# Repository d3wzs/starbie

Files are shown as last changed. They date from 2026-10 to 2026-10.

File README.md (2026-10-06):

# starbie

My starbie. In my variation of the starbie ive moved many of the comopenents around to have a cleaner and more organized front side. Its got a cool star design, inspired by a tomagotchi. 

Screenshot 2026-10-05 at 8 15 34 PM

Screenshot 2026-10-05 at 8 15 26 PM

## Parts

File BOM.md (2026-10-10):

# Starbie – bill of materials

<!-- Generated by Half Life from project cmuvdiqbu00kp01rk4xfdjdbk. Edits here are overwritten on the next sync. -->
<!-- Generated: 2026-10-09T00:31:55.839Z -->

> [!NOTE]
> This parts list is mirrored from [Half Life](https://halflife.hackclub.com). Editing it here will not change the platform's copy, and the next sync overwrites this file.

| Week | Tier | Parts funding |
| --- | --- | --- |
| Week 1 | Tier 1 | $30.00 |

| Part | What it's for | Qty | Unit | Total | Vendor |
| --- | --- | --- | --- | --- | --- |
| [XIAO ESP32 C3](https://www.seeedstudio.com/Seeed-XIAO-ESP32C3-p-5431.html) | Main loop | 1 | $4.90 | $4.90 | [Seeedstudio](https://www.seeedstudio.com/Seeed-XIAO-ESP32C3-p-5431.html) |
| [0.96 OLED](https://www.amazon.com/dp/B0GBVWBWCR) | displaying | 1 | $5.99 | $5.99 | [Amazon](https://www.amazon.com/dp/B0GBVWBWCR) |
| [MPU6050](https://www.amazon.com/2PCS-Unsoldered-GY-521-MPU6050-Sensor/dp/B0H9JC8XZL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) | sensing movement | 1 | $2.79 | $2.79 | [Amazon](https://www.amazon.com/2PCS-Unsoldered-GY-521-MPU6050-Sensor/dp/B0H9JC8XZL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) |
| [DHT11](https://www.amazon.com/DHT-11-Digital-Temperature-Humidity-Arduino/dp/B0CRRXJ83F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) | sensing temp/humidity | 1 | $3.78 | $3.78 | [Amazon](https://www.amazon.com/DHT-11-Digital-Temperature-Humidity-Arduino/dp/B0CRRXJ83F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) |
| [MX Switches](https://www.amazon.com//dp/B0FQP8VYX4) | clicking/interacting | 2 | $0.18 | $0.36 | [Amazon](https://www.amazon.com//dp/B0FQP8VYX4) |
| [Keycaps](https://www.amazon.com/dp/B0CQ2XG16M?th=1) | making keys pleasent to click | 2 | $0.60 | $1.20 | [Amazon](https://www.amazon.com/dp/B0CQ2XG16M?th=1) |
| [PCB](https://www.jlcpcb.com/) | connecting parts | 1 | $4.00 | $4.00 | [JLCPCB](https://www.jlcpcb.com/) |
| **Parts subtotal** | — | — | — | **$23.02** | — |
| **Tax & shipping** | — | — | — | **$2.76** | — |
| **Total** | — | — | — | **$25.78** | — |

$4.22 left of the tier's funding.

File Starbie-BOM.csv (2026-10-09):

Item | amount | cost (ea.) | Link
XIAO ESP32 C3 | 1 | 5.00 | https://www.seeedstudio.com/Seeed-XIAO-ESP32C3-p-5431.html
0.96 OLED | 1 | 2.50 | https://www.amazon.com/dp/B0GBVWBWCR
MPU6050 | 1 | 2.29 | https://www.amazon.com/dp/B0943SGP34
DHT11 | 1 | 3.33 | https://www.amazon.com/dp/B0BLG7R99R
MX Switches | 4 | 0.18 | https://www.amazon.com//dp/B0FQP8VYX4
Keycaps | 4 | 0.60 | https://www.amazon.com/dp/B0CQ2VLMVY
10k Resistor | 1 | 0.05 | https://www.amazon.com/dp/B0B4JFPHTW
PCB | 1 | 10.00 | https://www.jlcpcb.com/
Total (each kit) | 1 | 24.95

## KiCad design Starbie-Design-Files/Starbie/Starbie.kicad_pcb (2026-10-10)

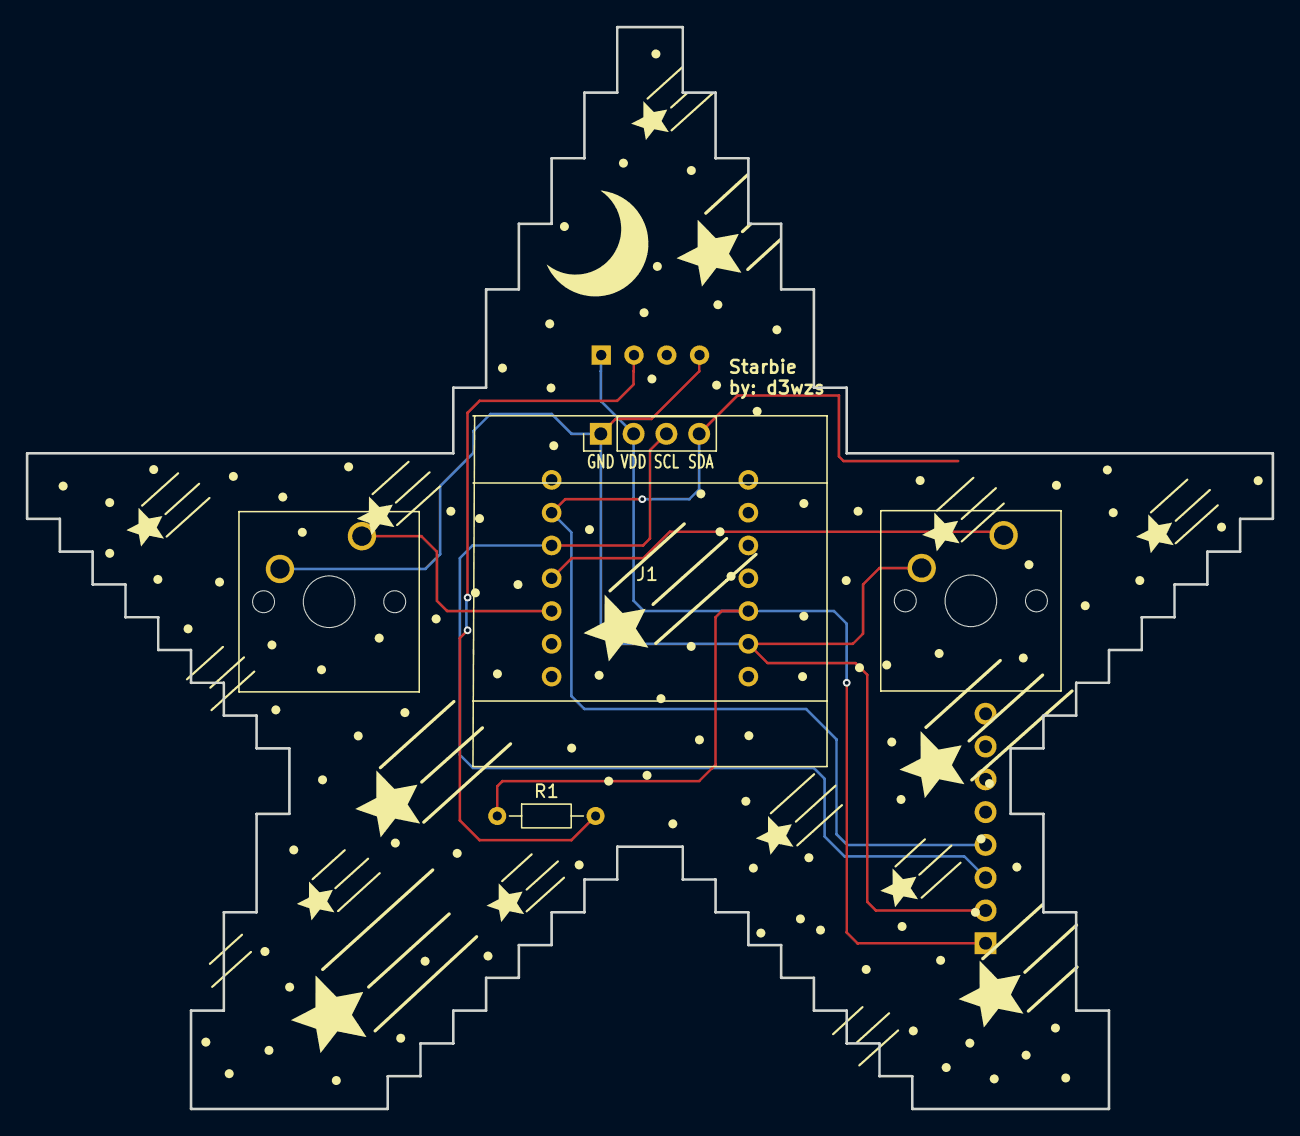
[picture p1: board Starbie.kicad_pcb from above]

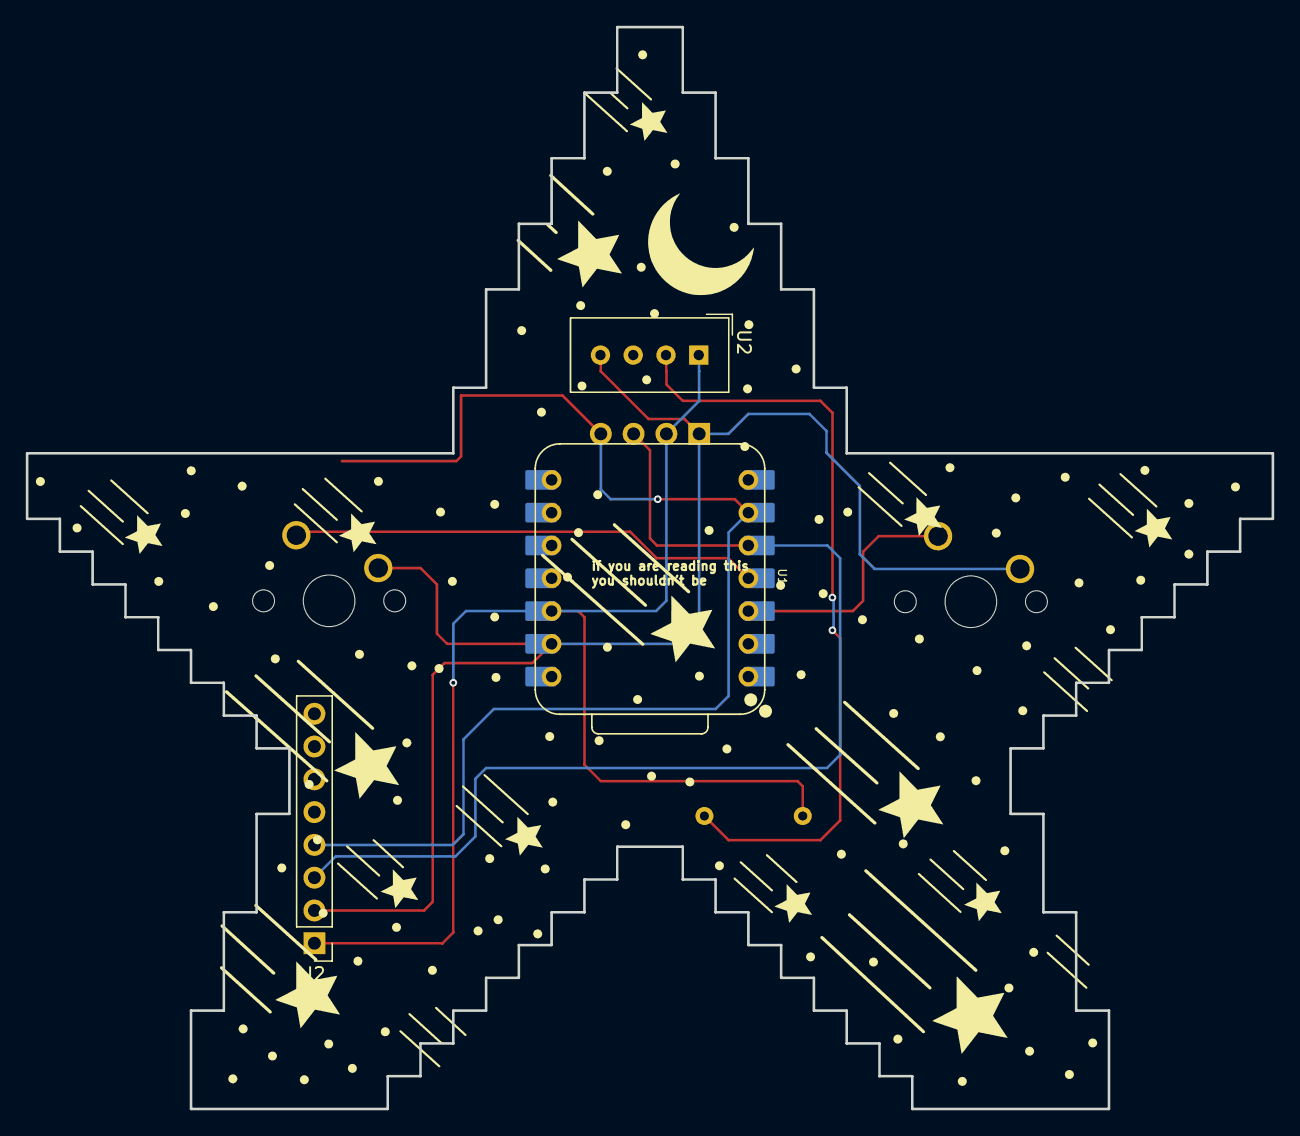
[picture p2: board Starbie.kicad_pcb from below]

Board: 2 copper layers, 96.5 x 83.8 mm, 7 parts (3 on the bottom side), 7 nets.

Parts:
J1: Conn_01x04_Pin; Display_128x64_096_I2C
J2: Conn_01x08_Pin; PinHeader_1x08_P2.54mm_Vertical
R1: 10K; R_Axial_DIN0204_L3.6mm_D1.6mm_P7.62mm_Horizontal
SW1, SW2: SW_Push; SW_Cherry_MX_1.00u_PCB
U1: XIAO-ESP32-C3-SMD; XIAO-ESP32-C6-DIP
U2: DHT11; Aosong_DHT11_5.5x12.0_P2.54mm

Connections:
+3.3V: J1.2, J2.1, R1.1, U1.12 (3V3_OUT), U2.1 (VDD)
/DHT11 DATA: R1.2, U2.2 (DATA)
/GPIO2: SW1.1, U1.3 (D2)
/GPIO3: SW2.1, U1.4 (D3)
/SCL: J1.3, J2.3, U1.5 (D4)
/SDA: J1.4, J2.4, U1.6 (D5)
GND: J1.1, J2.2, SW1.2, SW2.2, U1.13 (GND), U2.4 (GND)

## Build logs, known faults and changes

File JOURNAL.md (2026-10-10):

# Starbie – devlog

<!-- Generated by Half Life from project cmuvdiqbu00kp01rk4xfdjdbk. Edits here are overwritten on the next sync. -->
<!-- Generated: 2026-10-10T02:43:33.424Z -->

> [!NOTE]
> This devlog is mirrored from [Half Life](https://halflife.hackclub.com). Editing it here will not change the platform's copy, and the next sync overwrites this file.

> A tiny motion-controlled digital pet, basically a desktop Tamagotchi. Totally not a Starboy.

| Week | Tier | Hours logged | Entries |
| --- | --- | --- | --- |
| Week 1 | Tier 1 | 14.2h | 6 |

## Contents

1. [2026-10-05 – Created the schematic, then routed the board. I have yet to test it. Im going to try to get feedback on it from my friend who knowsmore then me. I wasted a good 45 mins trying to make a perfect star,](#2026-10-05-created-the-schematic-then-routed-the-board-i-hav)
2. [2026-10-05 – I worked on the PCB more now. I spent a good bit of time designing this shooting star pattern. Im hopping that the main board being behind the display wont be a problem, as well as there being no grou](#2026-10-05-i-worked-on-the-pcb-more-now-i-spent-a-good-bit-o)
3. [2026-10-06 – Variations!!](#2026-10-06-variations)
4. [2026-10-06 – Well that took longer then expected.](#2026-10-06-well-that-took-longer-then-expected)
5. [2026-10-08 – 14 hours for a bambu lab a1.](#2026-10-08-14-hours-for-a-bambu-lab-a1)
6. [2026-10-09 – Well I think its about time that I submit,](#2026-10-09-well-i-think-its-about-time-that-i-submit)

## Design

### 2026-10-05 – Created the schematic, then routed the board. I have yet to test it. Im going to try to get feedback on it from my friend who knowsmore then me. I wasted a good 45 mins trying to make a perfect star,

**3.3h**

Created the schematic, then routed the board. I have yet to test it. Im going to try to get feedback on it from my friend who knowsmore then me. I wasted a good 45 mins trying to make a perfect star, but then gave up and made my own version of a blocky star. I plan to add mounting holes to the design for future purposes as theres is space.

Screenshot 2026-10-05 at 5.34.42 PM

Screenshot 2026-10-05 at 5.34.16 PM

Screenshot 2026-10-05 at 5.34.02 PM

Screenshot 2026-10-05 at 5.33.51 PM

### 2026-10-05 – I worked on the PCB more now. I spent a good bit of time designing this shooting star pattern. Im hopping that the main board being behind the display wont be a problem, as well as there being no grou

**1.9h**

I worked on the PCB more now. I spent a good bit of time designing this shooting star pattern. Im hopping that the main board being behind the display wont be a problem, as well as there being no ground fill. Otherwise a slightly moved some compenents to make the board look better. Design Rules checker is all good, done for today.

Screenshot 2026-10-05 at 8.15.34 PM

Screenshot 2026-10-05 at 8.15.26 PM

### 2026-10-06 – Variations!!

**1.3h**

Variations!!

I decided that I would use the time I had this morning to work on my skills. More specifically my pcb routing skills. I routed a left button and right button variaty of my starbie. I had to move a few compents to fit the buttons in their spots however I think that the staarbies have kept their clean design.

Last night I read the journal guide. They are asking for alot, not something thats impossible, however it seems like something I would not look forward to. It kinda feels like an ELA class, which is something I want to get away from whilst doing these projects. However I will still try my best to make a nice journal.

I also added a few new decals in different spots to cover up the space from where the compenents where moved.

(edit: changed time from 1.2 - 1.3 because I realized at school that 1.2 is not one hour and 20 minutes, tuesday mornings am i right?)

Screenshot 2026-10-06 at 8.40.35 AM

Screenshot 2026-10-06 at 8.40.10 AM

### 2026-10-06 – Well that took longer then expected.

**2.7h**

Well that took longer then expected.

I was doing it completely wrong, I had no idea how to export the gerber files. That took up an hour of my time,  I could have been doing something better in that time but i learned something so thats what matters.

I read through the code that is provided and tried to understand what I could. I changed the starting values but thats It. I plan to do more with the code. I made a few changes to the pcbs but nothing major whatsoever

A big part of this time was spent doing organization. All of my files where scattered around my computer and many things needed to be added to the github. So I organized both my github repo and my computer. All the different versions of my stary starbie are in the repo

Ive been wondering how points are giving, maybe ill look through the documentation a little bit to find information. Is it aset amount for your time, you work or up to someone based of how good your project is? Very curious about this.

Thanks for reading, if you skipped to this, well idk.
Screenshot 2026-10-06 at 4.50.43 PM
organization
Screenshot 2026-10-06 at 4.48.26 PM
organization
Screenshot 2026-10-06 at 4.49.58 PM
seriously I dont know what else to say but organization.
Screenshot 2026-10-06 at 4.52.51 PM\
the impossible to get gerbers.

### 2026-10-08 – 14 hours for a bambu lab a1.

**2h**

14 hours for a bambu lab a1.

It seems like an impossible goal. But i will keep trying. Today I worked on basically just 2 things, one that was much harder and more confusing then the other.

First, the easier one, coding. I worked on coding the nescessary things for the starbie. I followed the instructions that are in the documentation, which are quite straight forward. After I finished doing the nescessary coding I uploaded the new version to my github. I might do some more customization of the sprite and more things once the starbie has been built but for now ill leave it.

Secondly (also lastly), I worked on making a bill of materials. At first i exported it from the schematic with help from some tutorials. But then I noticed that the starbie documentation has a bill of materials. So my shortcut finding self used that instead of making my own. I undestand how each switch is 18 cents but you have to buy it in an 100 pack... so does hackclub purchase the 100 pack, give me the 2 that I need then distribute the rest to others. Im considering inquiring about this.

Thanks for reading here are some photos =)

Screenshot 2026-10-08 at 5.43.12 PM

Screenshot 2026-10-08 at 5.43.25 PMo

### 2026-10-09 – Well I think its about time that I submit,

**3h**

Well I think its about time that I submit,

I went over a few last things and double checked how the pcb would look with some 3d models. Im not sure where to find 3D models so I just downloaded some moderatly sketchy ones which worked about half of the time. Everything looked good so I moved on from that.

I checked my github for any problems. I tried to calculate shipping but I had issues figuring that out so i just found the tax amount in my home provinces taxe amount. Im sure they will tell me I need to fix something before they approve it, but im not sure what.

Thanks for reading my last starbie design journal (maybe).

EDIT:
Yeah i decided i need those 14 hours for my precious bambu labs A1. So i spent a hot minute (like 2 hours) working on cleaning up the star design on all 3 versions as well as putting it on the back of the board. I added a little bit of text saying 'starbie by d3wzy', yeah yeah its not my original idea but whatever. Then i painfully updated all of the github project files and gerbers. Not a fun time, finally im now finishing this week


attempt at a banner photo


the design with 3d models, i also did it for the left button version.

EDIT IMAGES:


i dont know what to call this

prior to adding design to back

design on back!!

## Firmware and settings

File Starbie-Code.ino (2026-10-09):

#include <Wire.h>
#include <Adafruit_GFX.h>
#include <Adafruit_SSD1306.h>
#include <Adafruit_MPU6050.h>
#include <DHT.h>
#include <Preferences.h>
#include <math.h>

// =========================== BEGINNER SETTINGS ===========================
// Everything most builders will want to customize is in this one section.

// --- Your board's pins ----------------------------------------------------
// These are ESP32-C3 GPIO numbers, with the XIAO pin labels beside them.
const int I2C_SDA_PIN = 6;       // XIAO D4: OLED + MPU6050 SDA
const int I2C_SCL_PIN = 7;       // XIAO D5: OLED + MPU6050 SCL
const int DHT_PIN = 3;           // XIAO D1: DHT11 data
const int BUTTON_ONE_PIN = 4;    // XIAO D2: opens/confirms the radial menu
const int BUTTON_TWO_PIN = 5;    // XIAO D3: shows/hides stats

// Set this to false if your submission does not have a DHT11.
const bool USE_DHT11 = true;

// Most parts use these addresses. Only change them if an I2C scanner says
// your part is different (common OLED alternative: 0x3D).
const uint8_t OLED_ADDRESS = 0x3C;
const uint8_t MPU6050_ADDRESS = 0x68;

// --- Starting stats -------------------------------------------------------
// Stats are 0 to 100. They only change when you select an action or shake
// Starbie; nothing slowly drains while it sits on your desk.
const int STARTING_JOY = 75;
const int STARTING_ENERGY = 75;
const int STARTING_FULLNESS = 65;

// Set true, upload once, then set it back to false if you want a fresh pet.
const bool RESET_SAVED_PET_ON_BOOT = false;

// --- Radial menu ----------------------------------------------------------
// These four actions appear at TOP, RIGHT, BOTTOM, then LEFT in the menu.
// The last word controls the matching little visual reaction.
enum PetReaction {
  NAP_REACTION,
  JUMP_REACTION,
  HEART_REACTION,
  RUN_REACTION,
};

struct MenuItem {
  const char *label;
  int joyChange;
  int energyChange;
  int fullnessChange;
  PetReaction reaction;
};

const MenuItem MENU_ITEMS[] = {
  {"NAP",   1,  18, -4, NAP_REACTION},   // top: sleep and emit Zs
  {"PLAY", 12, -9, -5, RUN_REACTION},    // right: two fast laps + hearts
  {"FEED",  3,  2,  18, JUMP_REACTION},  // bottom: wiggle and jump
  {"PET",   7,  0,  0, HEART_REACTION},  // left: jump and emit hearts
};
const int MENU_ITEM_COUNT = sizeof(MENU_ITEMS) / sizeof(MENU_ITEMS[0]);

// --- Movement feel --------------------------------------------------------
// Bigger MENU_TILT_LIMIT makes the menu ball move less.
const float MENU_TILT_LIMIT = 6.0f;

// MPU6050 orientation: change these settings instead of rewiring your board.
// 1. If the sensor is turned 90 degrees, set SWAP_MPU_AXES to true.
// 2. If a direction feels backwards, change that direction from 1.0f to -1.0f.
const bool SWAP_MPU_AXES = false;
const float MENU_X_DIRECTION = 1.0f;
const float MENU_Y_DIRECTION = -1.0f;

// A small dead zone makes the ball rest in the center until the board is tilted.
const float MENU_CENTER_DEADZONE = 0.8f;
const float SHAKE_THRESHOLD = 7.0f;

// Shake is the only movement that has an effect outside the radial menu.
const int SHAKE_JOY_CHANGE = 5;
const int SHAKE_ENERGY_CHANGE = -2;
const int SHAKE_FULLNESS_CHANGE = -1;

// --- Your pet's bitmap and animation -------------------------------------
// This is a simplified 32 by 32, one-bit version of the supplied character.
// You can replace it with your own art later; keep these size values matched
// to the sprite array you paste in.
const int PET_SPRITE_WIDTH = 32;
const int PET_SPRITE_HEIGHT = 32;

// The pet wanders unless it is asleep. A non-nap action does a tiny shake,
// then a jump, except PLAY which runs two fast laps.
const uint16_t PET_WALK_PIXEL_MS = 70;
const uint16_t PET_PRE_JUMP_MS = 230;
const uint16_t PET_JUMP_MS = 430;
const int PET_JUMP_HEIGHT = 16;
const uint32_t NAP_DURATION_MS = 48000;  // 48 seconds: four times the old nap.
const uint16_t HEARTS_DURATION_MS = 1600;
const uint16_t PLAY_LAP_MS = 800;
const uint8_t PLAY_LAP_COUNT = 2;

// Each byte stores eight pixels, left to right. This sparse outline keeps the
// supplied creature readable on a tiny, one-bit OLED: head, eye, legs, tail,
// and a small flower-like ear accent all stay separate instead of becoming a blob.
const uint8_t PROGMEM PET_SPRITE[] = {
  0x00, 0x00, 0x00, 0x00,
  0x00, 0x00, 0x00, 0x00,
  0x00, 0x00, 0x00, 0x00,
  0x00, 0x00, 0x00, 0x00,
  0x00, 0x00, 0x00, 0x00,
  0x00, 0x00, 0x00, 0x00,
  0x00, 0x70, 0x0a, 0x00,
  0x00, 0xf8, 0x1f, 0x00,
  0x00, 0x8c, 0x3f, 0x80,
  0x00, 0x43, 0xff, 0x00,
  0x00, 0x43, 0xff, 0x00,
  0x00, 0x30, 0x7e, 0x00,
  0x00, 0x98, 0x01, 0x00,
  0x01, 0x98, 0x01, 0x80,
  0x03, 0x00, 0x10, 0xc0,
  0x03, 0x04, 0x00, 0xc0,
  0x01, 0x8b, 0x01, 0x80,
  0x01, 0xcb, 0x03, 0x80,
  0x03, 0xc0, 0x03, 0xc0,
  0x03, 0xc0, 0x03, 0xc0,
  0x01, 0xc0, 0x03, 0x80,
  0x01, 0x80, 0x01, 0x80,
  0x00, 0x60, 0x06, 0x00,
  0x00, 0x3f, 0xfc, 0x00,
  0x00, 0x7f, 0xfe, 0x00,
  0x00, 0x70, 0x0e, 0x00,
  0x00, 0x00, 0x00, 0x00,
  0x00, 0x00, 0x00, 0x00,
  0x00, 0x00, 0x00, 0x00,
  0x00, 0x00, 0x00, 0x00,
  0x00, 0x00, 0x00, 0x00,
  0x00, 0x00, 0x00, 0x00,
};
// ===========================================================================
// You can read below without needing to understand every line. The rest of
// the sketch handles buttons, sensors, drawing, and saving automatically.

const int SCREEN_WIDTH = 128;
const int SCREEN_HEIGHT = 64;
const int MENU_CENTER_X = 64;
const int MENU_CENTER_Y = 32;
const int MENU_ITEM_X[] = {64, 108, 64, 20};
const int MENU_ITEM_Y[] = {12, 32, 53, 32};
const int MENU_BALL_X_RANGE = 37;
const int MENU_BALL_Y_RANGE = 22;
const uint16_t BUTTON_DEBOUNCE_MS = 30;
const uint16_t MPU_READ_INTERVAL_MS = 30;
const uint16_t DHT_READ_INTERVAL_MS = 2200;
const uint16_t SHAKE_COOLDOWN_MS = 650;
const float STANDARD_GRAVITY = 9.80665f;

Adafruit_SSD1306 display(SCREEN_WIDTH, SCREEN_HEIGHT, &Wire, -1);
Adafruit_MPU6050 mpu;
DHT dht(DHT_PIN, DHT11);
Preferences preferences;

struct PetState {
  int joy;
  int energy;
  int fullness;
};

struct ButtonState {
  int pin;
  bool stableState;
  bool lastRawState;
  uint32_t lastChangedAt;
};

enum View {
  PET_VIEW,
  MENU_VIEW,
  STATS_VIEW,
};

PetState pet = {STARTING_JOY, STARTING_ENERGY, STARTING_FULLNESS};
ButtonState buttonOne = {BUTTON_ONE_PIN, HIGH, HIGH, 0};
ButtonState buttonTwo = {BUTTON_TWO_PIN, HIGH, HIGH, 0};
View currentView = PET_VIEW;

bool mpuFound = false;
bool dhtFound = false;
float accelerationX = 0.0f;
float accelerationY = 0.0f;
float accelerationZ = STANDARD_GRAVITY;
float temperatureC = NAN;
float humidity = NAN;
float menuBallX = MENU_CENTER_X;
float menuBallY = MENU_CENTER_Y;
float menuCenterAccelerationX = 0.0f;
float menuCenterAccelerationY = 0.0f;
int selectedMenuItem = -1;
uint32_t lastMpuReadAt = 0;
uint32_t lastDhtReadAt = 0;
uint32_t lastShakeAt = 0;
uint32_t shakeAnimationEndsAt = 0;
uint32_t petJumpStartedAt = 0;
uint32_t nappingUntil = 0;
uint32_t heartAnimationEndsAt = 0;
uint32_t playRunStartedAt = 0;
int nappingPetX = 0;

int petWalkingX(uint32_t now);

int keepInRange(int value, int smallest, int largest) {
  return constrain(value, smallest, largest);
}

void changePet(int joyChange, int energyChange, int fullnessChange) {
  pet.joy = keepInRange(pet.joy + joyChange, 0, 100);
  pet.energy = keepInRange(pet.energy + energyChange, 0, 100);
  pet.fullness = keepInRange(pet.fullness + fullnessChange, 0, 100);
}

void loadPet() {
  preferences.begin("starbie", false);
  if (RESET_SAVED_PET_ON_BOOT) {
    preferences.clear();
  }
  pet.joy = preferences.getInt("joy", STARTING_JOY);
  pet.energy = preferences.getInt("energy", STARTING_ENERGY);
  pet.fullness = preferences.getInt("full", STARTING_FULLNESS);
}

void savePet() {
  preferences.putInt("joy", pet.joy);
  preferences.putInt("energy", pet.energy);
  preferences.putInt("full", pet.fullness);
}

void setUpButton(ButtonState &button) {
  pinMode(button.pin, INPUT_PULLUP);
  button.stableState = digitalRead(button.pin);
  button.lastRawState = button.stableState;
  button.lastChangedAt = millis();
}

// Returns true exactly once for each press, even if the switch bounces.
bool wasPressed(ButtonState &button) {
  const bool rawState = digitalRead(button.pin);
  const uint32_t now = millis();

  if (rawState != button.lastRawState) {
    button.lastRawState = rawState;
    button.lastChangedAt = now;
  }

  if (rawState != button.stableState &&
      now - button.lastChangedAt >= BUTTON_DEBOUNCE_MS) {
    button.stableState = rawState;
    return button.stableState == LOW;
  }

  return false;
}

void updateMpu() {
  if (!mpuFound || millis() - lastMpuReadAt < MPU_READ_INTERVAL_MS) {
    return;
  }
  lastMpuReadAt = millis();

  sensors_event_t acceleration;
  sensors_event_t gyro;
  sensors_event_t sensorTemperature;
  mpu.getEvent(&acceleration, &gyro, &sensorTemperature);
  accelerationX = acceleration.acceleration.x;
  accelerationY = acceleration.acceleration.y;
  accelerationZ = acceleration.acceleration.z;
}

void updateDht() {
  if (!dhtFound || millis() - lastDhtReadAt < DHT_READ_INTERVAL_MS) {
    return;
  }
  lastDhtReadAt = millis();

  const float newHumidity = dht.readHumidity();
  const float newTemperatureC = dht.readTemperature();
  if (!isnan(newHumidity)) {
    humidity = newHumidity;
  }
  if (!isnan(newTemperatureC)) {
    temperatureC = newTemperatureC;
  }
}

int petWalkingX(uint32_t now) {
  const int farthestX = SCREEN_WIDTH - PET_SPRITE_WIDTH;
  const uint32_t roundTrip = static_cast<uint32_t>(farthestX) * 2;
  const uint32_t step = (now / PET_WALK_PIXEL_MS) % roundTrip;
  return step <= farthestX ? step : roundTrip - step;
}

uint32_t playRunDuration() {
  return static_cast<uint32_t>(PLAY_LAP_MS) * PLAY_LAP_COUNT;
}

bool isNapping() {
  return nappingUntil != 0 && millis() < nappingUntil;
}

bool isPlaying() {
  return playRunStartedAt != 0 && millis() - playRunStartedAt < playRunDuration();
}

int playRunX(uint32_t now) {
  const int farthestX = SCREEN_WIDTH - PET_SPRITE_WIDTH;
  const uint32_t lapAge = (now - playRunStartedAt) % PLAY_LAP_MS;
  const float progress = static_cast<float>(lapAge) / PLAY_LAP_MS;
  return progress < 0.5f ? static_cast<int>(progress * 2.0f * farthestX)
                         : static_cast<int>((1.0f - progress) * 2.0f * farthestX);
}

void updatePetTimers() {
  if (nappingUntil != 0 && !isNapping()) {
    nappingUntil = 0;  // The pet wakes naturally when its nap time is over.
  }
  if (playRunStartedAt != 0 && !isPlaying()) {
    playRunStartedAt = 0;  // PLAY is exactly two left-to-right-to-left laps.
  }
}

// While the menu is open, the MPU6050 acts like a tiny air mouse. The position
// at the instant Button 1 opens the menu becomes the center for that menu use.
void updateMenuBall() {
  float xTilt = accelerationX - menuCenterAccelerationX;
  float yTilt = accelerationY - menuCenterAccelerationY;

  if (SWAP_MPU_AXES) {
    const float oldXTilt = xTilt;
    xTilt = yTilt;
    yTilt = oldXTilt;
  }
  xTilt = constrain(xTilt * MENU_X_DIRECTION, -MENU_TILT_LIMIT, MENU_TILT_LIMIT);
  yTilt = constrain(yTilt * MENU_Y_DIRECTION, -MENU_TILT_LIMIT, MENU_TILT_LIMIT);
  const float targetX = MENU_CENTER_X + (xTilt / MENU_TILT_LIMIT) * MENU_BALL_X_RANGE;
  const float targetY = MENU_CENTER_Y + (yTilt / MENU_TILT_LIMIT) * MENU_BALL_Y_RANGE;

  // This small amount of smoothing makes the ball feel less jittery.
  menuBallX += (targetX - menuBallX) * 0.20f;
  menuBallY += (targetY - menuBallY) * 0.20f;

  // The menu has four full sectors, not four tiny targets. Any tilt direction
  // past the center dead zone selects its matching top/right/bottom/left action.
  if (fabsf(xTilt) < MENU_CENTER_DEADZONE && fabsf(yTilt) < MENU_CENTER_DEADZONE) {
    selectedMenuItem = -1;
  } else if (fabsf(xTilt) > fabsf(yTilt)) {
    selectedMenuItem = xTilt > 0.0f ? 1 : 3;  // right or left
  } else {
    selectedMenuItem = yTilt > 0.0f ? 2 : 0;  // bottom or top
  }
}

void checkForShake() {
  if (!mpuFound || currentView != PET_VIEW) {
    return;
  }

  const float magnitude = sqrtf(accelerationX * accelerationX +
                                accelerationY * accelerationY +
                                accelerationZ * accelerationZ);
  const uint32_t now = millis();
  if (fabsf(magnitude - STANDARD_GRAVITY) >= SHAKE_THRESHOLD &&
      now - lastShakeAt >= SHAKE_COOLDOWN_MS) {
    lastShakeAt = now;
    nappingUntil = 0;  // A shake wakes a sleeping pet right away.
    shakeAnimationEndsAt = now + 350;
    changePet(SHAKE_JOY_CHANGE, SHAKE_ENERGY_CHANGE, SHAKE_FULLNESS_CHANGE);
    savePet();
  }
}

void openMenu() {
  currentView = MENU_VIEW;
  selectedMenuItem = -1;
  menuBallX = MENU_CENTER_X;
  menuBallY = MENU_CENTER_Y;
  // Calibrate here so every menu starts from however the builder is holding it.
  menuCenterAccelerationX = accelerationX;
  menuCenterAccelerationY = accelerationY;
}

void chooseMenuItem() {
  if (selectedMenuItem == -1) {
    return;  // Keep the menu open until the ball reaches a choice.
  }

  const MenuItem &item = MENU_ITEMS[selectedMenuItem];
  changePet(item.joyChange, item.energyChange, item.fullnessChange);
  savePet();
  const uint32_t now = millis();
  nappingUntil = 0;
  heartAnimationEndsAt = 0;
  playRunStartedAt = 0;

  if (item.reaction == NAP_REACTION) {
    petJumpStartedAt = 0;
    nappingPetX = petWalkingX(now);
    nappingUntil = now + NAP_DURATION_MS;
  } else if (item.reaction == RUN_REACTION) {
    petJumpStartedAt = 0;
    playRunStartedAt = now;
    heartAnimationEndsAt = now + playRunDuration();
  } else {
    // A confirmed action gets a little anticipation shake before the jump.
    petJumpStartedAt = now;
    if (item.reaction == HEART_REACTION) {
      heartAnimationEndsAt = now + HEARTS_DURATION_MS;
    }
  }
  currentView = PET_VIEW;
}

void handleButtons() {
  if (wasPressed(buttonOne)) {
    if (currentView == MENU_VIEW) {
      chooseMenuItem();
    } else {
      openMenu();
    }
  }

  if (wasPressed(buttonTwo)) {
    // Button 2 never changes the pet. It only lets you peek at the values.
    currentView = currentView == STATS_VIEW ? PET_VIEW : STATS_VIEW;
  }
}

void drawSparkle(int x, int y) {
  display.drawPixel(x, y - 2, SSD1306_WHITE);
  display.drawPixel(x - 1, y - 1, SSD1306_WHITE);
  display.drawPixel(x + 1, y - 1, SSD1306_WHITE);
  display.drawPixel(x - 2, y, SSD1306_WHITE);
  display.drawPixel(x, y, SSD1306_WHITE);
  display.drawPixel(x + 2, y, SSD1306_WHITE);
  display.drawPixel(x - 1, y + 1, SSD1306_WHITE);
  display.drawPixel(x + 1, y + 1, SSD1306_WHITE);
  display.drawPixel(x, y + 2, SSD1306_WHITE);
}

void drawHeart(int x, int y) {
  // A tiny seven-pixel-wide heart that stays crisp on the OLED.
  display.fillRect(x - 2, y, 2, 2, SSD1306_WHITE);
  display.fillRect(x + 1, y, 2, 2, SSD1306_WHITE);
  display.fillRect(x - 3, y + 2, 7, 2, SSD1306_WHITE);
  display.fillRect(x - 2, y + 4, 5, 1, SSD1306_WHITE);
  display.fillRect(x - 1, y + 5, 3, 1, SSD1306_WHITE);
  display.drawPixel(x, y + 6, SSD1306_WHITE);
}

void drawHearts(uint32_t now, int petX, int petY) {
  if (now >= heartAnimationEndsAt) {
    return;
  }

  const float progress =
      1.0f - static_cast<float>(heartAnimationEndsAt - now) / HEARTS_DURATION_MS;
  const int rise = static_cast<int>(progress * 18.0f);
  drawHeart(petX + 10, petY - 3 - rise);
  drawHeart(petX + 22, petY - 9 - rise / 2);
}

void drawSleepZs(uint32_t now, int petX, int petY) {
  // The Zs float upward, then loop back down while the pet is napping.
  const int rise = static_cast<int>((now / 300UL) % 15UL);
  display.setTextSize(1);
  display.setTextColor(SSD1306_WHITE);
  display.setCursor(petX + 23, petY - 2 - rise);
  display.print("z");
  display.setCursor(petX + 28, petY - 8 - rise / 2);
  display.print("z");
}

void drawPet() {
  display.clearDisplay();

  const uint32_t now = millis();
  int petX = isNapping() ? nappingPetX : petWalkingX(now);
  if (isPlaying()) {
    petX = playRunX(now);
  }
  int petY = SCREEN_HEIGHT - PET_SPRITE_HEIGHT;

  // The pet always wanders except during a nap; PLAY temporarily takes over.
  if (now < shakeAnimationEndsAt) {
    petX += static_cast<int>(sinf(now / 18.0f) * 3.0f);
  }

  if (!isNapping() && petJumpStartedAt != 0) {
    const uint32_t animationAge = now - petJumpStartedAt;

    if (animationAge < PET_PRE_JUMP_MS) {
      petX += static_cast<int>(sinf(now / 16.0f) * 3.0f);
    } else if (animationAge < PET_PRE_JUMP_MS + PET_JUMP_MS) {
      const float jumpProgress =
          static_cast<float>(animationAge - PET_PRE_JUMP_MS) / PET_JUMP_MS;
      petY -= static_cast<int>(sinf(jumpProgress * PI) * PET_JUMP_HEIGHT);
    } else {
      petJumpStartedAt = 0;
    }
  }

  petX = constrain(petX, 0, SCREEN_WIDTH - PET_SPRITE_WIDTH);
  display.drawBitmap(petX, petY, PET_SPRITE, PET_SPRITE_WIDTH, PET_SPRITE_HEIGHT, SSD1306_WHITE);
  if (!isNapping() && (now / 250) % 2 == 0) {
  drawSparkle(petX - 4, petY + 18);
  }

  if (isNapping()) {
    drawSleepZs(now, petX, petY);
  }
  drawHearts(now, petX, petY);
}

void drawMenuItem(int item) {
  const int boxWidth = 33;
  const int boxHeight = 12;
  const int boxX = MENU_ITEM_X[item] - boxWidth / 2;
  const int boxY = MENU_ITEM_Y[item] - boxHeight / 2;
  const bool isSelected = item == selectedMenuItem;

  if (isSelected) {
    display.fillRoundRect(boxX, boxY, boxWidth, boxHeight, 3, SSD1306_WHITE);
    display.setTextColor(SSD1306_BLACK);
  } else {
    display.drawRoundRect(boxX, boxY, boxWidth, boxHeight, 3, SSD1306_WHITE);
    display.setTextColor(SSD1306_WHITE);
  }

  display.setTextSize(1);
  const int labelLength = strlen(MENU_ITEMS[item].label);
  display.setCursor(MENU_ITEM_X[item] - labelLength * 3, MENU_ITEM_Y[item] - 3);
  display.print(MENU_ITEMS[item].label);
  display.setTextColor(SSD1306_WHITE);
}

void drawMenu() {
  display.clearDisplay();
  // The two diagonal lines divide the screen into four big selection sectors.
  display.drawLine(0, 0, SCREEN_WIDTH - 1, SCREEN_HEIGHT - 1, SSD1306_WHITE);
  display.drawLine(0, SCREEN_HEIGHT - 1, SCREEN_WIDTH - 1, 0, SSD1306_WHITE);
  for (int item = 0; item < MENU_ITEM_COUNT; item++) {
    drawMenuItem(item);
  }

  display.drawCircle(MENU_CENTER_X, MENU_CENTER_Y, 11, SSD1306_WHITE);
  display.fillCircle(static_cast<int>(menuBallX), static_cast<int>(menuBallY), 4,
                     SSD1306_WHITE);
}

void drawStatBar(int y, const char *label, int value) {
  display.setTextSize(1);
  display.setTextColor(SSD1306_WHITE);
  display.setCursor(4, y);
  display.print(label);
  display.drawRect(48, y, 57, 8, SSD1306_WHITE);
  display.fillRect(49, y + 1, map(value, 0, 100, 0, 55), 6, SSD1306_WHITE);
  display.setCursor(109, y);
  display.print(value);
}

void drawStats() {
  display.clearDisplay();
  drawStatBar(5, "JOY", pet.joy);
  drawStatBar(20, "ENERGY", pet.energy);
  drawStatBar(35, "FULL", pet.fullness);

  display.setCursor(4, 53);
  if (!isnan(temperatureC)) {
    display.print("TEMP ");
    display.print(static_cast<int>(temperatureC));
    display.print("C");
  } else {
    display.print("TEMP --");
  }

  display.setCursor(76, 53);
  if (!isnan(humidity)) {
    display.print("H ");
    display.print(static_cast<int>(humidity));
    display.print("%");
  } else {
    display.print("H --");
  }
}

void drawCurrentView() {
  if (currentView == MENU_VIEW) {
    drawMenu();
  } else if (currentView == STATS_VIEW) {
    drawStats();
  } else {
    drawPet();
  }
  display.display();
}

void setup() {
  Serial.begin(115200);
  Wire.begin(I2C_SDA_PIN, I2C_SCL_PIN);
  setUpButton(buttonOne);
  setUpButton(buttonTwo);
  loadPet();

  if (!display.begin(SSD1306_SWITCHCAPVCC, OLED_ADDRESS)) {
    Serial.println("OLED not found. Check power, GND, SDA, SCL, and address.");
    while (true) {
      delay(10);
    }
  }

  mpuFound = mpu.begin(MPU6050_ADDRESS, &Wire);
  if (mpuFound) {
    mpu.setAccelerometerRange(MPU6050_RANGE_8_G);
    mpu.setGyroRange(MPU6050_RANGE_500_DEG);
    mpu.setFilterBandwidth(MPU6050_BAND_21_HZ);
  } else {
    Serial.println("MPU6050 not found. The menu will not move until it is connected.");
  }

  if (USE_DHT11) {
    dht.begin();
    dhtFound = true;
  }

  drawCurrentView();
}

void loop() {
  updateMpu();
  updateDht();
  updatePetTimers();
  handleButtons();

  if (currentView == MENU_VIEW) {
    updateMenuBall();
  } else {
    checkForShake();
  }

  drawCurrentView();
  delay(16);  // Smooth display updates without making the code complicated.
}

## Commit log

2026-10-06 upload starbie gerber files
2026-10-06 upload design files
    [Starbie.kicad_pcb, Starbie.kicad_sch]
2026-10-06 move gerber
2026-10-09 upload bom
    [Starbie.csv]
